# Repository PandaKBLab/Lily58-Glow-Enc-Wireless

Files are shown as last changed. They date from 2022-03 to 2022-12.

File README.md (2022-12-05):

# Lily58 × qtkb Glow + Rotary Encoders designed for Wireless

Lily58 is 6×4+4keys column-staggered split keyboard.

This is a project to edit the Lily58 x qtkb Glow + Rotary Encoders to make it easily compatible with wireless settings. This is designed for the nice!nano, and will have a battery disconnect switch, no TRRS jack, and underglow LEDs (a later task is to add per-key LEDs). Very much a work in progress until there is an initial release. Hoping to have this modified and ready shortly after I receive my Boardsource.xyz Lulu (Lily58 compatible) case. Stay tuned!

Firmware repo: https://github.com/iasoren/Lily58-Glow-Enc-Wireless-ZMK

| Task | Status | Issues | ETA |
|---|---|---|---|
| Schematic | Pending | Need to fix underglow | Unknown |
| PCB layouts | Pending | Trying to revert to dual-sided design | Unknown |
| Underglow | Pending | See above | Unknown |
| Backlight | Planning | Planning | Undetermined |

Bill of Materials:
* 2x PCB
* 4x OS102011MA1QN1 Slide Switch
* 2x nice!nano
* 1x EC11 encoder (or 2x, personal preference)
* 56x Hotswap sockets
* 60x SK6812 mini-E LEDs
* 20x WS2812b LEDs
* 58x 1N4148W Thru-hole Diodes (or SMD diodes)

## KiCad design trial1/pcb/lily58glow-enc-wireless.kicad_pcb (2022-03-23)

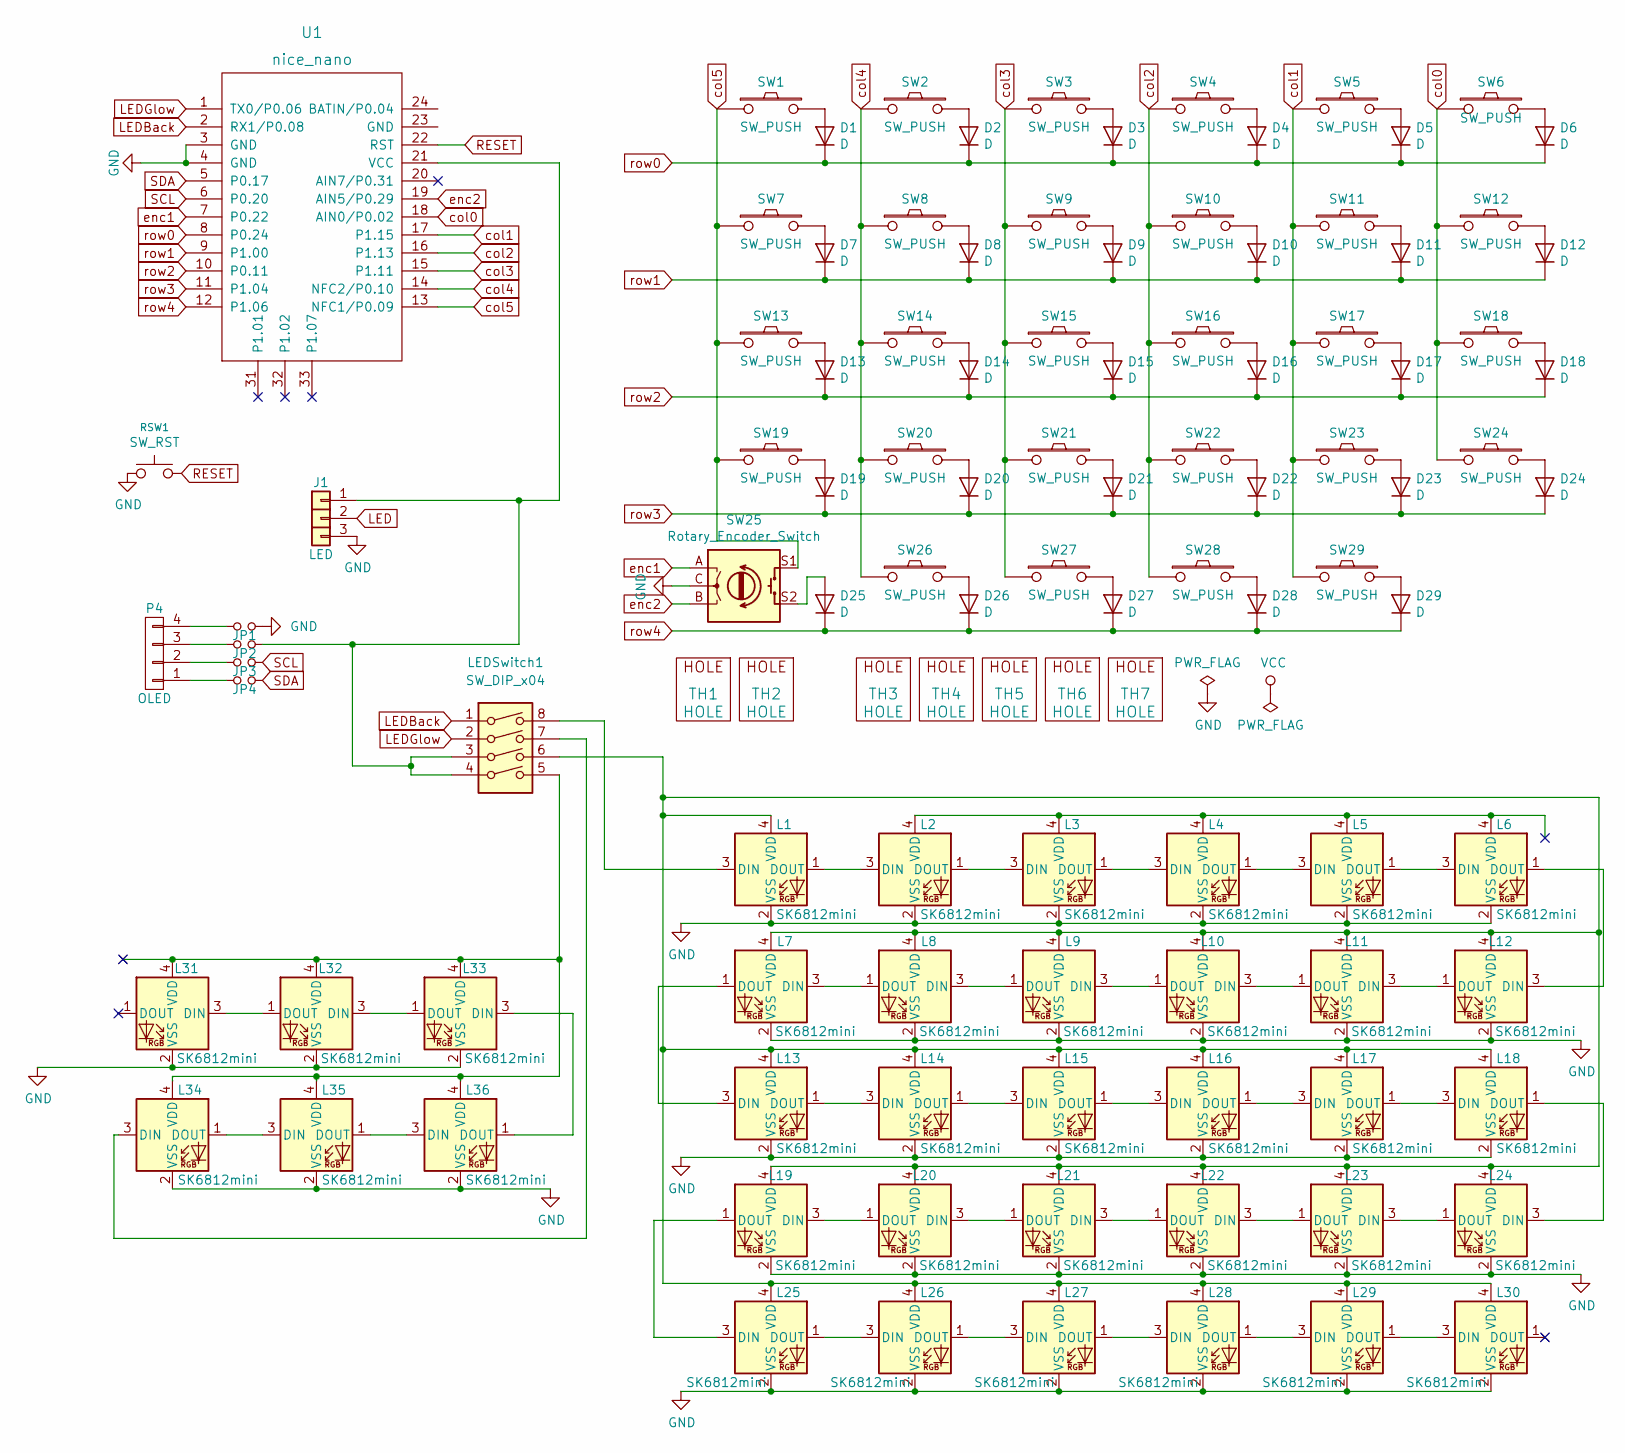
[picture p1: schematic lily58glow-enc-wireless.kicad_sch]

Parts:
D1, D2, D3, D4, D5, D6, D7, D8, D9, D10, D11, D12, D13, D14, D15, D16, D17, D18, D19, D20, D21, D22, D23, D24, D25, D26, D27, D28, D29: D; Diode_TH_SOD123
J1: LED; StripLED
JP1, JP2, JP3, JP4: Jumper_NO_Small; Jumper
L1, L2, L3, L4, L5, L6, L7, L8, L9, L10, L11, L12, L13, L14, L15, L16, L17, L18, L19, L20, L21, L22, L23, L24, L25, L26, L27, L28, L29, L30: SK6812mini; SK6812MINI_rev
L31, L32, L33, L34, L35, L36: SK6812mini; SK6812MINI_underglow_rev
LEDSwitch1: SW_DIP_x04; DIP-8_W7.62mm_Socket
P4: OLED; MY_SIL-4
RSW1: SW_RST; TACT_SWITCH_TVBP06
SW1, SW2, SW3, SW4, SW5, SW6, SW7, SW8, SW9, SW10, SW11, SW12, SW13, SW14, SW15, SW16, SW17, SW18, SW19, SW20, SW21, SW22, SW23, SW24, SW27, SW28, SW29: SW_PUSH; MX_PG1350_FLIP_HOLES_18mm
SW25: Rotary_Encoder_Switch; RotaryEncoder_Alps_EC11E-Switch_Vertical_H20mm
SW26: SW_PUSH; MX_PG1350_FLIP_HOLES_27mm
TH1, TH2: HOLE; HOLE_M2
TH3, TH4, TH5, TH6, TH7: HOLE; HOLE_M2_TH
U1: nice_nano

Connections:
GND: J1.3, JP1.2, L1.2 (VSS), L2.2 (VSS), L3.2 (VSS), L4.2 (VSS), L5.2 (VSS), L6.2 (VSS), L7.2 (VSS), L8.2 (VSS), L9.2 (VSS), L10.2 (VSS), L11.2 (VSS), L12.2 (VSS), L13.2 (VSS), L14.2 (VSS), L15.2 (VSS), L16.2 (VSS), L17.2 (VSS), L18.2 (VSS), L19.2 (VSS), L20.2 (VSS), L21.2 (VSS), L22.2 (VSS), L23.2 (VSS), L24.2 (VSS), L25.2 (VSS), L26.2 (VSS), L27.2 (VSS), L28.2 (VSS), L29.2 (VSS), L30.2 (VSS), L31.2 (VSS), L32.2 (VSS), L33.2 (VSS), L34.2 (VSS), L35.2 (VSS), L36.2 (VSS), RSW1.1, SW25.C, U1.3 (GND), U1.4 (GND)
LED: J1.2
LEDBack: LEDSwitch1.1, U1.2 (RX1/P0.08)
LEDGlow: LEDSwitch1.2, U1.1 (TX0/P0.06)
unnamed: D1.2 (A), SW1.2
unnamed: D2.2 (A), SW2.2
unnamed: D3.2 (A), SW3.2
unnamed: D4.2 (A), SW4.2
unnamed: D5.2 (A), SW5.2
unnamed: D6.2 (A), SW6.2
unnamed: D7.2 (A), SW7.2
unnamed: D8.2 (A), SW8.2
unnamed: D9.2 (A), SW9.2
unnamed: D10.2 (A), SW10.2
unnamed: D11.2 (A), SW11.2
unnamed: D12.2 (A), SW12.2
unnamed: D13.2 (A), SW13.2
unnamed: D14.2 (A), SW14.2
unnamed: D15.2 (A), SW15.2
unnamed: D16.2 (A), SW16.2
unnamed: D17.2 (A), SW17.2
unnamed: D18.2 (A), SW18.2
unnamed: D19.2 (A), SW19.2
unnamed: D20.2 (A), SW20.2
unnamed: D21.2 (A), SW21.2
unnamed: D22.2 (A), SW22.2
unnamed: D23.2 (A), SW23.2
unnamed: D24.2 (A), SW24.2
unnamed: D25.2 (A), SW25.S2
unnamed: D26.2 (A), SW26.2
unnamed: D27.2 (A), SW27.2
unnamed: D28.2 (A), SW28.2
unnamed: D29.2 (A), SW29.2
unnamed: J1.1, JP2.2, LEDSwitch1.3, LEDSwitch1.4, U1.21 (VCC)
unnamed: JP1.1, P4.4
unnamed: JP2.1, P4.3
unnamed: JP3.1, P4.2
unnamed: JP4.1, P4.1
unnamed: L1.1 (DOUT), L2.3 (DIN)
unnamed: L1.3 (DIN), LEDSwitch1.8
unnamed: L1.4 (VDD), L7.4 (VDD), L8.4 (VDD), L9.4 (VDD), L10.4 (VDD), L11.4 (VDD), L12.4 (VDD), L13.4 (VDD), L14.4 (VDD), L15.4 (VDD), L16.4 (VDD), L17.4 (VDD), L18.4 (VDD), L19.4 (VDD), L20.4 (VDD), L21.4 (VDD), L22.4 (VDD), L23.4 (VDD), L24.4 (VDD), L25.4 (VDD), L26.4 (VDD), L27.4 (VDD), L28.4 (VDD), L29.4 (VDD), L30.4 (VDD), LEDSwitch1.6
unnamed: L2.1 (DOUT), L3.3 (DIN)
unnamed: L3.1 (DOUT), L4.3 (DIN)
unnamed: L4.1 (DOUT), L5.3 (DIN)
unnamed: L5.1 (DOUT), L6.3 (DIN)
unnamed: L7.3 (DIN), L8.1 (DOUT)
unnamed: L8.3 (DIN), L9.1 (DOUT)
unnamed: L9.3 (DIN), L10.1 (DOUT)
unnamed: L10.3 (DIN), L11.1 (DOUT)
unnamed: L11.3 (DIN), L12.1 (DOUT)
unnamed: L6.1 (DOUT), L12.3 (DIN)
unnamed: L13.1 (DOUT), L14.3 (DIN)
unnamed: L7.1 (DOUT), L13.3 (DIN)
unnamed: L14.1 (DOUT), L15.3 (DIN)
unnamed: L15.1 (DOUT), L16.3 (DIN)
unnamed: L16.1 (DOUT), L17.3 (DIN)
unnamed: L17.1 (DOUT), L18.3 (DIN)
unnamed: L18.1 (DOUT), L24.3 (DIN)
unnamed: L19.1 (DOUT), L25.3 (DIN)
unnamed: L19.3 (DIN), L20.1 (DOUT)
unnamed: L20.3 (DIN), L21.1 (DOUT)
unnamed: L21.3 (DIN), L22.1 (DOUT)
unnamed: L22.3 (DIN), L23.1 (DOUT)
unnamed: L23.3 (DIN), L24.1 (DOUT)
unnamed: L25.1 (DOUT), L26.3 (DIN)
unnamed: L26.1 (DOUT), L27.3 (DIN)
unnamed: L27.1 (DOUT), L28.3 (DIN)
unnamed: L28.1 (DOUT), L29.3 (DIN)
unnamed: L29.1 (DOUT), L30.3 (DIN)
unnamed: L31.3 (DIN), L32.1 (DOUT)
unnamed: L32.3 (DIN), L33.1 (DOUT)
unnamed: L33.3 (DIN), L36.1 (DOUT)
unnamed: L34.1 (DOUT), L35.3 (DIN)
unnamed: L34.3 (DIN), LEDSwitch1.7
unnamed: L35.1 (DOUT), L36.3 (DIN)
RESET: RSW1.2, U1.22 (RST)
SCL: JP3.2, U1.6 (P0.20)
SDA: JP4.2, U1.5 (P0.17)
col0: SW6.1, SW12.1, SW18.1, SW24.1, U1.18 (AIN0/P0.02)
col1: SW5.1, SW11.1, SW17.1, SW23.1, SW29.1, U1.17 (P1.15)
col2: SW4.1, SW10.1, SW16.1, SW22.1, SW28.1, U1.16 (P1.13)
col3: SW3.1, SW9.1, SW15.1, SW21.1, SW27.1, U1.15 (P1.11)
col4: SW2.1, SW8.1, SW14.1, SW20.1, SW26.1, U1.14 (NFC2/P0.10)
col5: SW1.1, SW7.1, SW13.1, SW19.1, SW25.S1, U1.13 (NFC1/P0.09)
enc1: SW25.A, U1.7 (P0.22)
enc2: SW25.B, U1.19 (AIN5/P0.29)
row0: D1.1 (K), D2.1 (K), D3.1 (K), D4.1 (K), D5.1 (K), D6.1 (K), U1.8 (P0.24)
row1: D7.1 (K), D8.1 (K), D9.1 (K), D10.1 (K), D11.1 (K), D12.1 (K), U1.9 (P1.00)
row2: D13.1 (K), D14.1 (K), D15.1 (K), D16.1 (K), D17.1 (K), D18.1 (K), U1.10 (P0.11)
row3: D19.1 (K), D20.1 (K), D21.1 (K), D22.1 (K), D23.1 (K), D24.1 (K), U1.11 (P1.04)
row4: D25.1 (K), D26.1 (K), D27.1 (K), D28.1 (K), D29.1 (K), U1.12 (P1.06)

Board: 2 copper layers, 110 parts (0 on the bottom side), 90 nets, no tracks yet.

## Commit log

2022-02-17 File Update
    Files update
    [Bottom Case v2.3mf, Foot 50mm v2.3mf, Lily Glow Enc Case.f3d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]
2022-02-18 Basic PCB updates
    Updated some silkscreen, have to learn how to use this program better
    [Lily58.kicad_pcb, lily58glow-enc-wireless.kicad_pcb, lily58glow-enc-wireless.kicad_sch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]
2022-02-20 Update file layout
    [lily58glow-enc-wireless.kicad_pcb, lily58glow-enc-wireless.kicad_sch, lily58glow-enc-wireless.sch]
2022-02-22 Updates to schematics
    Might just scrap all of the traces and start from scratch...
    [lily58glow-enc-wireless.kicad_pcb, lily58glow-enc-wireless.kicad_sch]
2022-02-23 Starting PCB from scratch, and making single sided boards
    [lily58glow-enc-wireless.kicad_pcb]
2022-03-23 Reverted to base model to try again
    [Lily58.kicad_pcb, Lily58.sch, lily58glow-enc-wireless.kicad_pcb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]
2022-03-28 Working on Vias
    [Lily58.kicad_pcb, Lily58.kicad_sch]
2022-04-01 Add libraries, new design
    Turns out DIP switches aren't rated for the LED current, so I need a SPDT switch with a diode placed in between. This means you can have the backlight on, none on, or the backlight and underglow on. I might reverse this decision later on. Who knows
    [Lily58.kicad_pcb, Lily58.kicad_sch]
2022-04-04 Some file structure changes + lib files
    [Lily58.kicad_pcb, Lily58.kicad_sch, Lily58.sch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]
2022-04-07 Some more wiring updates
    [Lily58.kicad_pcb, Lily58.kicad_sch]
2022-04-14 Updates to files and layout
    [Lily58.kicad_pcb, Lily58.kicad_sch, Lily58.sch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]
2022-05-03 Progress update
    Started on BOM, progress update
2022-05-04 File Cleanup
    Worked a bit more on LEDs, started initial firmware settings. Ordered some nice!nanos and soon to have prototype boards in to work with
    [Lily58.kicad_pcb, Lily58.kicad_sch, Lily58.sch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]
2022-05-04 remove files
    [Lily58.kicad_pcb, Lily58.kicad_sch, Lily58.sch]
2022-05-04 Added files back
    [Lily58.kicad_pcb, Lily58.kicad_sch, Lily58.sch]
2022-05-05 Backlight LEDs
    Finished the routing for backlight LEDs, adjusted nice!nano placement and power placement. Moved some text around to empty board spots, made sure that silkscreen was duplicated to both sides. Uploade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
    [Lily58-B_Cu.gbr, Lily58-B_Mask.gbr, Lily58-B_Silkscreen.gbr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]
2022-05-05 Moving firmware to separate repo
    Lily58-Glow-Enc-Wireless-ZMK
2022-05-27 Replacing V1
    Starting from scratch for V1 due to some issues
    [Lily58-B_Cu.gbr, Lily58-B_Mask.gbr, Lily58-B_Silkscreen.gbr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]
2022-05-27 Remove PCB
    [Lily58.kicad_pcb, Lily58.sch]
2022-05-27 Add V2 folder
    [Lily58.kicad_pcb, Lily58.sch]
2022-05-31 Fixes to V1
    Fixing V1 errors, v2 is working
    [Lily58.kicad_pcb, Lily58wireless.kicad_pcb, Lily58wireless.kicad_sch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]
2022-06-01 Hopefully Fixed PCB
    Added in the option to replace the right hand encoder with a switch, must be soldered though. Hopefully this PCB will work this time around!
    [Lily58-B_Cu.gbr, Lily58-B_Mask.gbr, Lily58-B_Silkscreen.gbr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]
2022-06-02 Keymap updates
    [Lily58.kicad_pcb]
2022-06-14 Folder Layout Updates
    [Lily58-B_Cu.gbr, Lily58-B_Mask.gbr, Lily58-B_Silkscreen.gbr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]
2022-06-15 Some edits
    Added in underglow LEDs to the schematics, started moving around the PCB items.
    Deciding between TH and SMD diodes (or both)
    [Lily58.kicad_sch]
2022-06-20 More PCB edits
    [Lily58.kicad_sch]
2022-09-28 Split keyboard PCB, remove LEDs
    Split the keyboard PCBs so it is no longer double sided, removed per-key lighting for this iteration due to ZMK support. Thinking about RP2040+wireless for a future iteration to add per-key lighting back in
    [Lily58.kicad_sch]
2022-09-29 Battery moving
    Moving battery solder points
